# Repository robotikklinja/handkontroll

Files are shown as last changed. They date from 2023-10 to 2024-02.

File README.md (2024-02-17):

# Handkontroll
En handkontroll med display basert på Arduino Nano

# BOM til handkontrollen

## Electronics components

Antal deler 27, 17 unike.
Totalt 185 NOK. Pris per elev inkludert frakt ekskludert moms når vi importerer til en klasse på 18 elever. 

## Alixpress linker
* [5PCS 20mm Shaft Potentiometer, 10K](https://www.aliexpress.com/item/1005001421294754.html)
* [8mm Metal Button Switch Normally Open Waterproof Antirust (GREEN)](https://www.aliexpress.com/item/1005002153423900.html)
* [8mm Metal Button Switch Normally Open Waterproof Antirust (RED)](https://www.aliexpress.com/item/1005002153423900.html)
* [8mm Metal Button Switch Normally Open Waterproof Antirust (BLUE)](https://www.aliexpress.com/item/1005002153423900.html)
* [8mm Metal Button Switch Normally Open Waterproof Antirust (YELLOW)](https://www.aliexpress.com/item/1005002153423900.html)
* [Arduino Nano 3.0 with usb cable](https://www.aliexpress.com/item/1005002509257579.html)
* [Usb  Male to Female Extension Cable 0.3m left-angle](https://www.aliexpress.com/item/4000819180471.html)
* [Wall Terminal Plug Type 5.08mm Pitch Connector Pcb Screw Terminal Block](https://www.aliexpress.com/item/4000907549303.html)
* [JST connector set, 2,54mm 20 mm wire. 2P](https://www.aliexpress.com/item/32954418743.html)
* [JST connector set, 2,54mm 20 mm wire. 4P](https://www.aliexpress.com/item/32954418743.html)
* [JST connector set, 2,54mm 20 mm wire. 5P](https://www.aliexpress.com/item/32954418743.html)
* [LCD module Blue Green screen IIC/I2C 1602](https://www.aliexpress.com/item/32685016568.html)
* [Battery clips 9V](https://www.aliexpress.com/item/1005003688602261.html)
* [Rocker Switch ON/OFF](https://www.aliexpress.com/item/4001165826718.html)
* [ 0.3A PPTC inline self recovery fuse/fuse 72V 300mA pin spacing 5mm](https://www.aliexpress.com/item/1005006054781697.html)
* [M3 6mm Standoff Nylon Plastic Hexagon Thread PCB ](https://www.aliexpress.com/item/1005004311987482.html)
* [15pin female header 2,54mm pitch](https://www.aliexpress.com/item/1005001621390463.html)
* [2.54 Wire Dupont Line female to  female 4P 20cm](https://www.aliexpress.com/item/1005003198478253.html)

[Excel BOM](handkontroll_ali_BOM.xlsx)

## Mekaniske deler
* 2 mm * 1000mm * 300 mm aluminium platemeteall per elev. Kjøp minst dobbel mengde.
* Popnagler
* Ø2.5 mm, Ø3 mm, Ø4mm maskinskruer og mutter
* Gummiføtter [$1,24 USD for 20pcs Conical Rubber Foot aliexpress](https://www.aliexpress.com/item/1005002995372007.html)

[Se denne for mekaniske tegninger](https://github.com/Jaknil/Arduino_material/tree/master/handkontroll)

## Verktøy
* Platesaks
* Plateknekker
* Filer
* Skrustikk
* Drill
* Gjengetapp
* Høreselvern
* Beskyttelsebriller

## 3D printer
* Elevene designer og printer knott til potentiometeren
* Fint å bruke til batteriholder [thingiverser, eksempel](https://www.thingiverse.com/thing:2144462)

## Kretstegning

Har laget en versjon med 2 knapper og en med 4. Knappene har innebygget LED lys i ulike ferger som kan dimmes med PWM. Alt er koblet til kortet med headers.

For at lage PCB-layout så har jeg måttet slettet knapper og LEDs fra koblingsskjema-vyen for at de ikke skall bli del av PCBen. 
Det finns forskjellige fritzing filer, noen viser alle deler, noen viser bare delene som er direkte på kretskortet, med headers for tilkobling.

### Two buttons
* [Koblingsskjema, alle deler PDF](handkontroll_full_schematic_all_components.pdf)
* [Fritzing fil med alle deler, OBS ikke riktig JST-header pin spacing for PCB på denne](handkontroll_full_schematic_all_components.fzz)
* [PCB, bare kortet, fritzing (riktig JST pin spacing)](handkontroll_full_schematic_pcb.fzz)
* 2 knapp PCB versjon. Bestillt fra fabrikk via deres integrerte tjenste [Se online](https://aisler.net/p/RCMDKGZY)

### 4 buttons
* Frtizing [PDF-koblingskjema bare kortet](handkontroll_full_schematic_pcb_4_buttons_schem.pdf)
* [PCB med 4 knapper bare kortet i fritzing ](handkontroll_full_schematic_pcb_4_buttons.fzz)
* 4 knapp versjon- Designet i fritzing,  Bestillt fra fabrikk via deres integrerte tjenste [Se kortet online](https://aisler.net/p/QSIZRARK)

#### Version log
1.3 Ordered Pcb
1.4 All LEDs pins now have PWM functionallity and the external power connector is now a JST-plug like the others
1.5 Merge switch and power connector to standardize them 
1.6 Auto-route traces (separate file)
  
| Antall kort  | Totalpris i € | Stykkpis i € |
| --- | --- | --- |
| 3 | 16 | 5,3 |
| 6 | 24 | 4 |
| 12 | 34 | 2,8 |
| 108 | 232 | 2,1 |

Shipping kostet 22€ med tracking 0€ uten trakking men tok då veldig lang tid.    

## Eksempelkode
* [KubenKoder repository](https://github.com/KubenKoder/Arduino/tree/master/Egna%20exempel/handkontroll)
* [Jaknil repository](https://github.com/Jaknil/Arduino_material/tree/master/handkontroll)

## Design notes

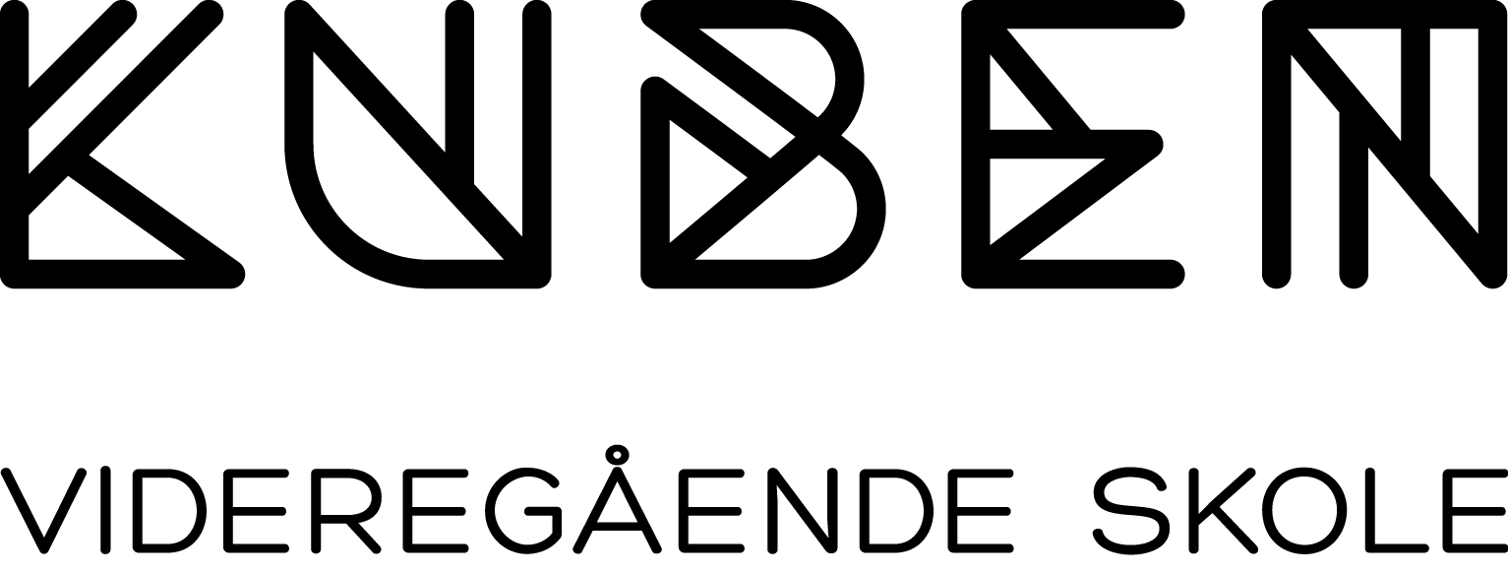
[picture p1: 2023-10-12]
kuben.png

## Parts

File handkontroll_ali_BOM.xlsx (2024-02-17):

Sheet: BOM
Varenr./lagernummer på aliexpress | Beskrivelse/navn på varen | tot Antall bestillt | Sum, USD eks mva, ink ship | Betalt NOK ink mva | Bruk per elev | Beregnet NOK per stk, ex MVA | Brukt pris per rad | Link
1005001421294750 | 5PCS 20mm Shaft Potentiometer, 10K | 25 | $8.01 | kr 111.00 | 1 | kr 3.55 | kr 3.55 | https://www.aliexpress.com/item/1005001421294754.html
1005002153423900 | 8mm Metal Button Switch Normally Open Waterproof Antirust (GREEN) | 25 | $179.00 | kr 2485.00 | 1 | kr 19.88 | kr 19.88 | https://www.aliexpress.com/item/1005002153423900.html
1005002153423900 | 8mm Metal Button Switch Normally Open Waterproof Antirust (RED) | 25 | $179.00 | kr 2485.00 | 1 | kr 19.88 | kr 19.88 | https://www.aliexpress.com/item/1005002153423900.html
1005002153423900 | 8mm Metal Button Switch Normally Open Waterproof Antirust (BLUE) | 25 | $179.00 | kr 2485.00 | 1 | kr 19.88 | kr 19.88 | https://www.aliexpress.com/item/1005002153423900.html
1005002153423900 | 8mm Metal Button Switch Normally Open Waterproof Antirust (YELLOW) | 25 | $179.00 | kr 2485.00 | 1 | kr 19.88 | kr 19.88 | https://www.aliexpress.com/item/1005002153423900.html
1005002509257579 | Arduino Nano 3.0 with usb cable | 25 | $66.19 | kr 895.00 | 1 | kr 28.64 | kr 28.64 | https://www.aliexpress.com/item/1005002509257579.html
4000819180471 | Usb Male to Female Extension Cable 0.3m left-angle | 25 | $37.91 | kr 524.00 | 1 | kr 16.77 | kr 16.77 | https://www.aliexpress.com/item/4000819180471.html
4000907549303 | Wall Terminal Plug Type 5.08mm Pitch Connector Pcb Screw Terminal Block | 25 | $27.49 | kr 380.00 | 1 | kr 12.16 | kr 12.16 | https://www.aliexpress.com/item/4000907549303.html
32954418743 | JST connector set, 2,54mm 20 mm wire. 2P | 130 | $70.00 | kr 966.00 | 2 | kr 1.49 | kr 2.97 | https://www.aliexpress.com/item/32954418743.html
32954418743 | JST connector set, 2,54mm 20 mm wire. 4P | 130 | $70.00 | kr 966.00 | 6 | kr 1.49 | kr 8.92 | https://www.aliexpress.com/item/32954418743.html
32954418743 | JST connector set, 2,54mm 20 mm wire. 5P | 130 | $70.00 | kr 966.00 | 0 | kr 1.49 | kr 0.00 | https://www.aliexpress.com/item/32954418743.html
32685016568 | LCD module Blue Green screen IIC/I2C 1602 | 25 | $49.72 | kr 703.00 | 1 | kr 22.50 | kr 22.50 | https://www.aliexpress.com/item/32685016568.html
1005003688602261 | Battery clips 9V | 40 | $6.25 | kr 86.00 | 1 | kr 1.72 | kr 1.72 | https://www.aliexpress.com/item/1005003688602261.html
4001165826718 | Rocker Switch ON/OFF | 30 | $3.94 | kr 54.00 | 1 | kr 1.44 | kr 1.44 | https://www.aliexpress.com/item/4001165826718.html
1005006054781697 | 0.3A PPTC inline self recovery fuse/fuse 72V 300mA pin spacing 5mm | 100 | $8.25 | kr 114.00 | 1 | kr 0.91 | kr 0.91 | https://www.aliexpress.com/item/1005006054781697.html
1005004311987482 | M3 6mm Standoff Nylon Plastic Hexagon Thread PCB | 100 | $4.69 | kr 65.00 | 4 | kr 0.52 | kr 2.08 | https://www.aliexpress.com/item/1005004311987482.html
1005001621390463 | 15pin female header 2,54mm pitch | 60 | $4.63 | kr 64.00 | 2 | kr 0.85 | kr 1.71 | https://www.aliexpress.com/item/1005001621390463.html
1005003198478253 | 2.54 Wire Dupont Line female to female 4P 20cm | 40 | $7.56 | kr 104.00 | 1 | kr 2.08 | kr 2.08 | https://www.aliexpress.com/item/1005003198478253.html
 |  | Total |  | kr 15938.00 | 27 | Total kostnad per handkontroll | kr 184.96

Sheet: IOs 1.6
Configuration | Name | Pin | Function | Special function
Input | Button1 | D2 | Start
Output | Led1 | D3 |  | PWM
Input | Button2 | D4 | Stop
Output | Led2 | D5 |  | PWM
Output | Led3 | D6 |  | PWM
Input | Button3 | D7 | -1 sekund
Input | Button4 | D8 | +1 sekund
Output | Led4 | D9 |  | PWM
Output | PWM_Motor | D10 |  | PWM
Output | Direction_Motor | D11 |  | PWM
Output | Run_Motor | D12
Output | Speaker | D13
Input | Potentiometer | A0 |  | AnalogRead
SDA_I2C | LCD_Screen | A4 |  | I2C
SCL_I2C | LCD_Screen | A5 |  | I2C

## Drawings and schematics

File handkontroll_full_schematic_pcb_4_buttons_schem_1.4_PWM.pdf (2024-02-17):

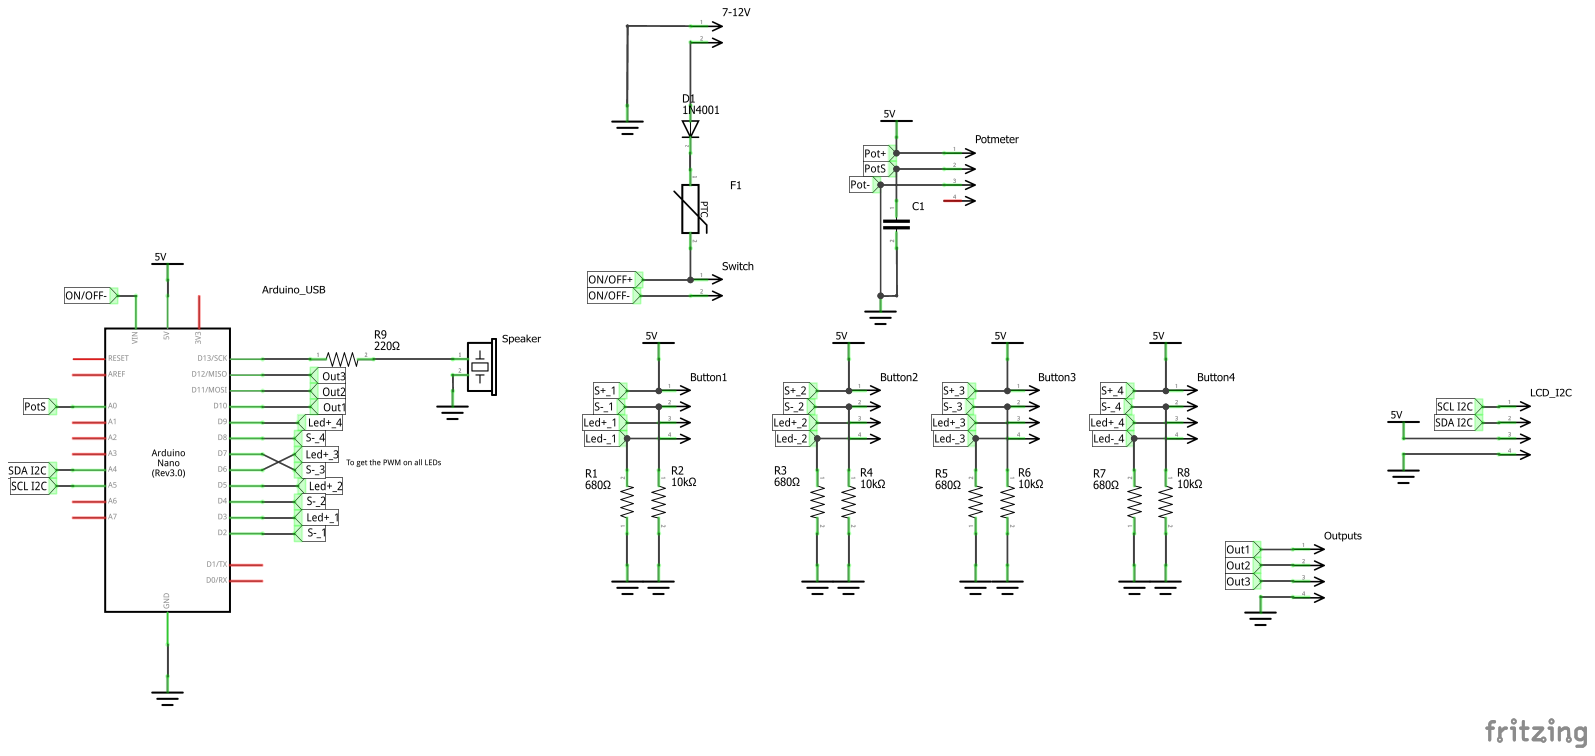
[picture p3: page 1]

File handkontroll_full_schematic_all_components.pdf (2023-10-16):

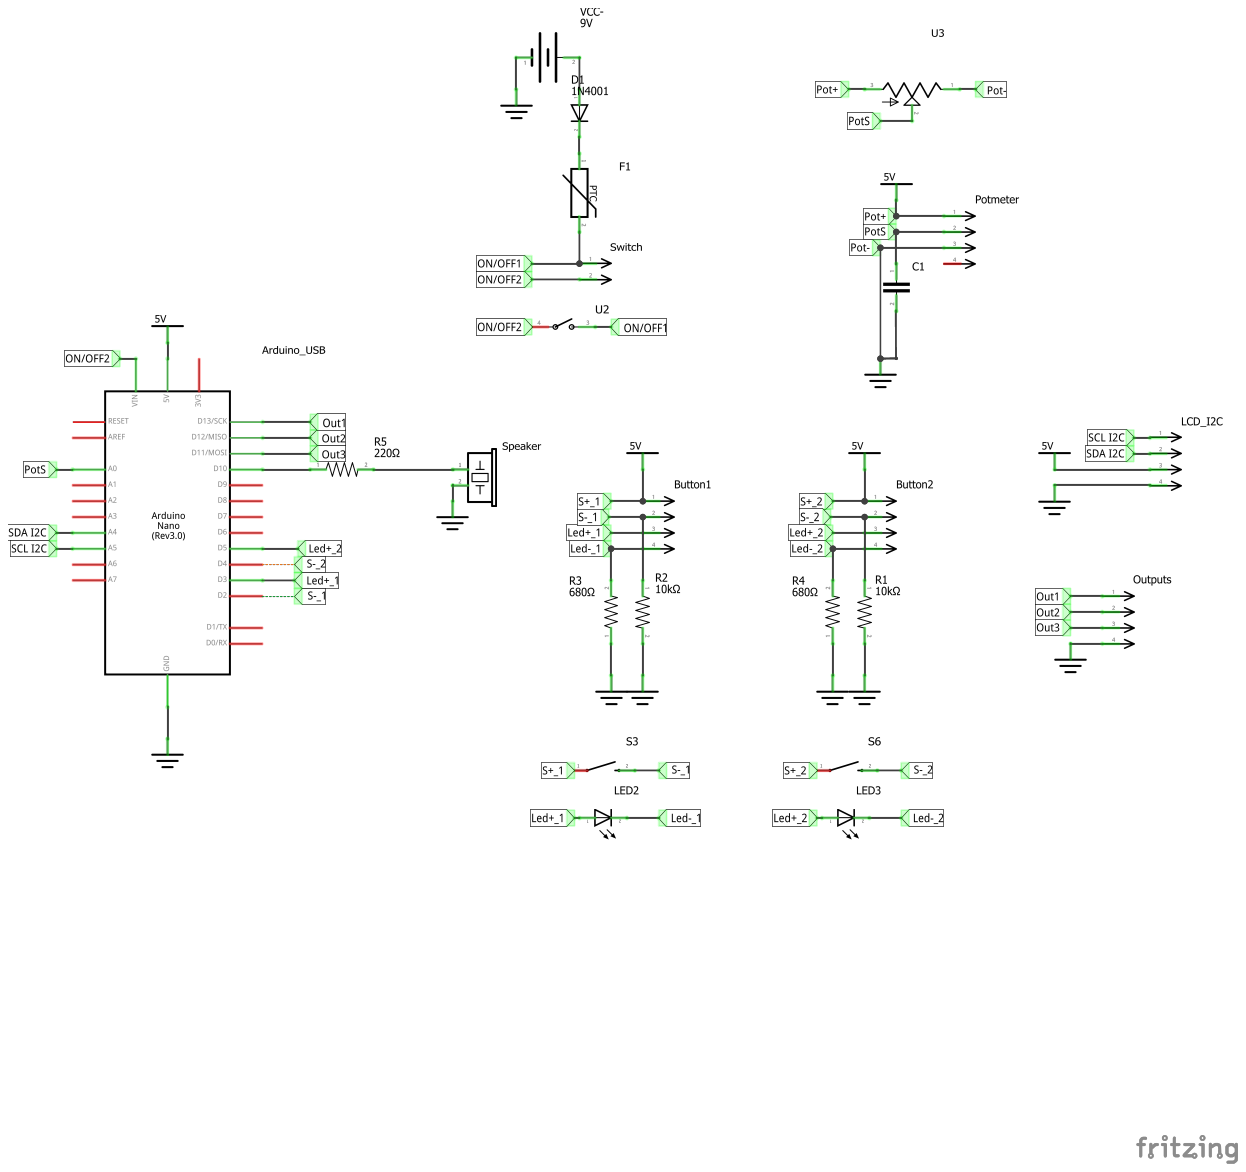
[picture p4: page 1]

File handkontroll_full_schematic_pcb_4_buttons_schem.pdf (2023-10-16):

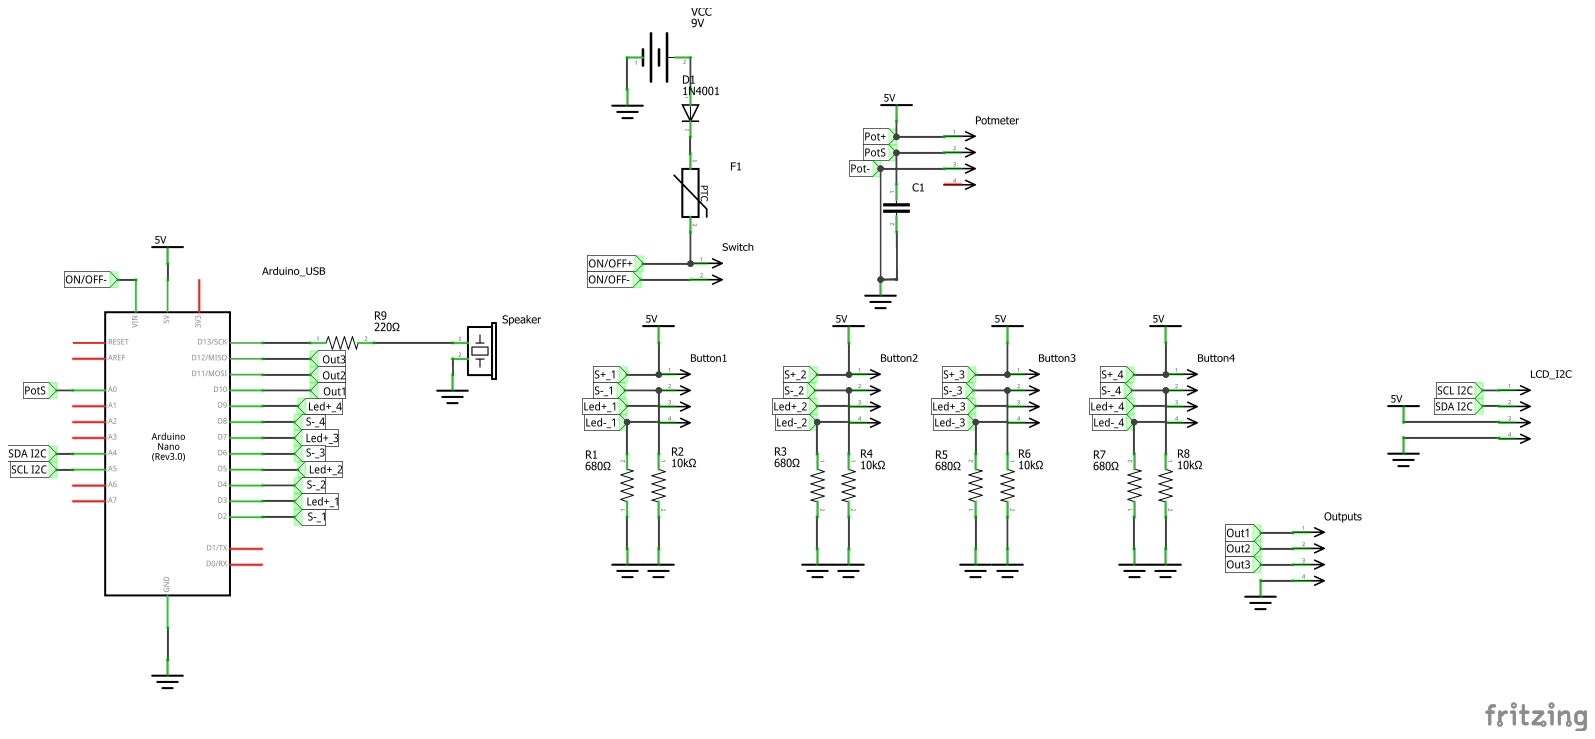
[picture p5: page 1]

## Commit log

2023-10-11 PCB for handkontroll
    [handkontroll_ali_BOM.xlsx, handkontroll_full_schematic.fzz, handkontroll_full_schematic_pcb.fzz]
2023-10-16 added version with all components for 2 buttons
    [handkontroll_full_schematic_all_components.fzz]
2024-02-17 Improved pin use and standardized connectors
    [handkontroll_ali_BOM.xlsx, handkontroll_full_schematic_pcb_4_buttons.fzz, handkontroll_full_schematic_pcb_4_buttons_auto_test.fzz]
2024-02-17 Kode fra Ki.osloskolen.no
    [handkontroll_ali_BOM.xlsx]
